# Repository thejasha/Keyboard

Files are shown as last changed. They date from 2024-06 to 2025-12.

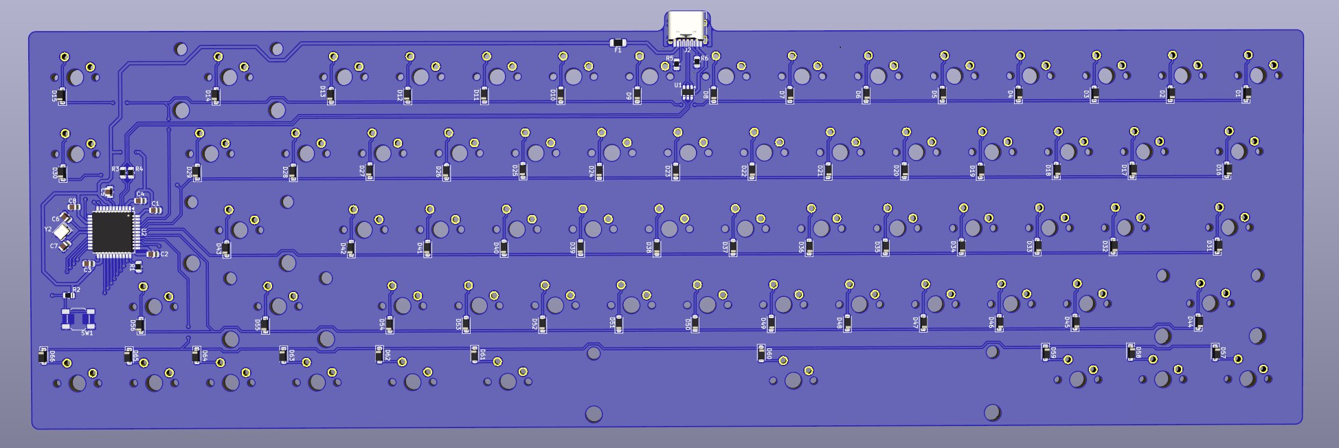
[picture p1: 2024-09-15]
Boardback.jpg

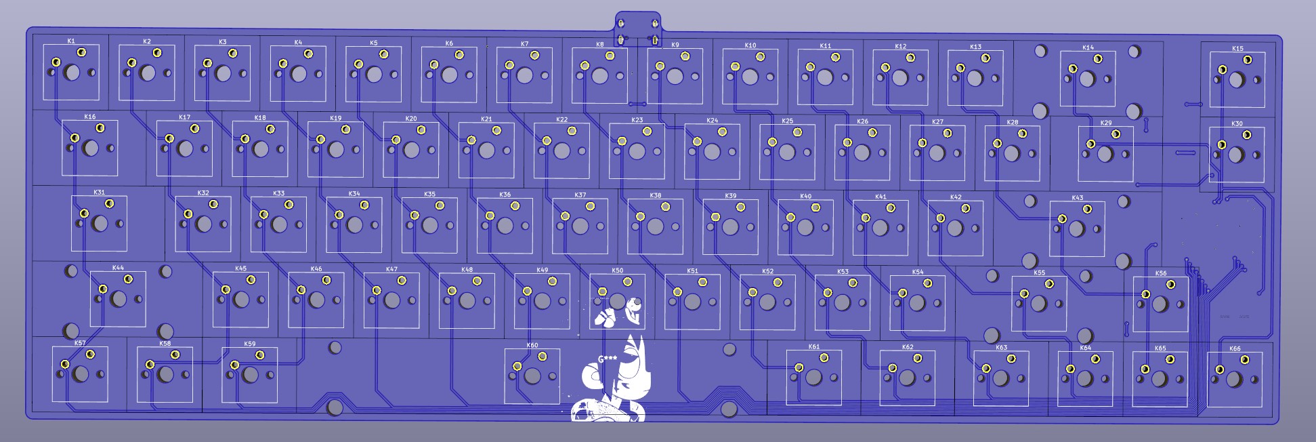
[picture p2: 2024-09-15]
Boardfront.jpg

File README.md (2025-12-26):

# Keyboard

Leopold fC660m schematic and PCB layout which are contained in 65 folder - can import whole folder as project in Kicad.



Boardfront



## Firmware
Download QMK MSYS, compile aacustomboard, and then flash it on MCU (Follow documenation on QMK site). aacustomboard files will only work the exact pinout from 65 files.

https://docs.qmk.fm/newbs_getting_started 

board

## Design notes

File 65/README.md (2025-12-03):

First attempt at making a Leopold fc660m style board, will not be doing leds for now.

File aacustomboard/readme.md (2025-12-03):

# aacustomboard

aacustomboard

*A short description of the keyboard/project*

* Keyboard Maintainer: [Josh Amann](https://github.com/thejasha/)
* Hardware Supported: *The PCBs, controllers supported*
* Hardware Availability: *Manufacter the 65 kicad file lol*

Make example for this keyboard (after setting up your build environment):

    make aacustomboard:default

Flashing example for this keyboard:

    make aacustomboard:default:flash

See the [build environment setup](https://docs.qmk.fm/#/getting_started_build_tools) and the [make instructions](https://docs.qmk.fm/#/getting_started_make_guide) for more information. Brand new to QMK? Start with our [Complete Newbs Guide](https://docs.qmk.fm/#/newbs).

## Bootloader

Enter the bootloader in 3 ways:

* **Bootmagic reset**: Hold down the key at (0,0) in the matrix (usually the top left key or Escape) and plug in the keyboard
* **Physical reset button**: Briefly press the button on the back of the PCB - some may have pads you must short instead [THIS ONE EASY]
* **Keycode in layout**: Press the key mapped to `QK_BOOT` if it is available

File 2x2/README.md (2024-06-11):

# Keyboard
First attempt using kicad. Learning how to design schematic and pcb by making a 2x2 board.

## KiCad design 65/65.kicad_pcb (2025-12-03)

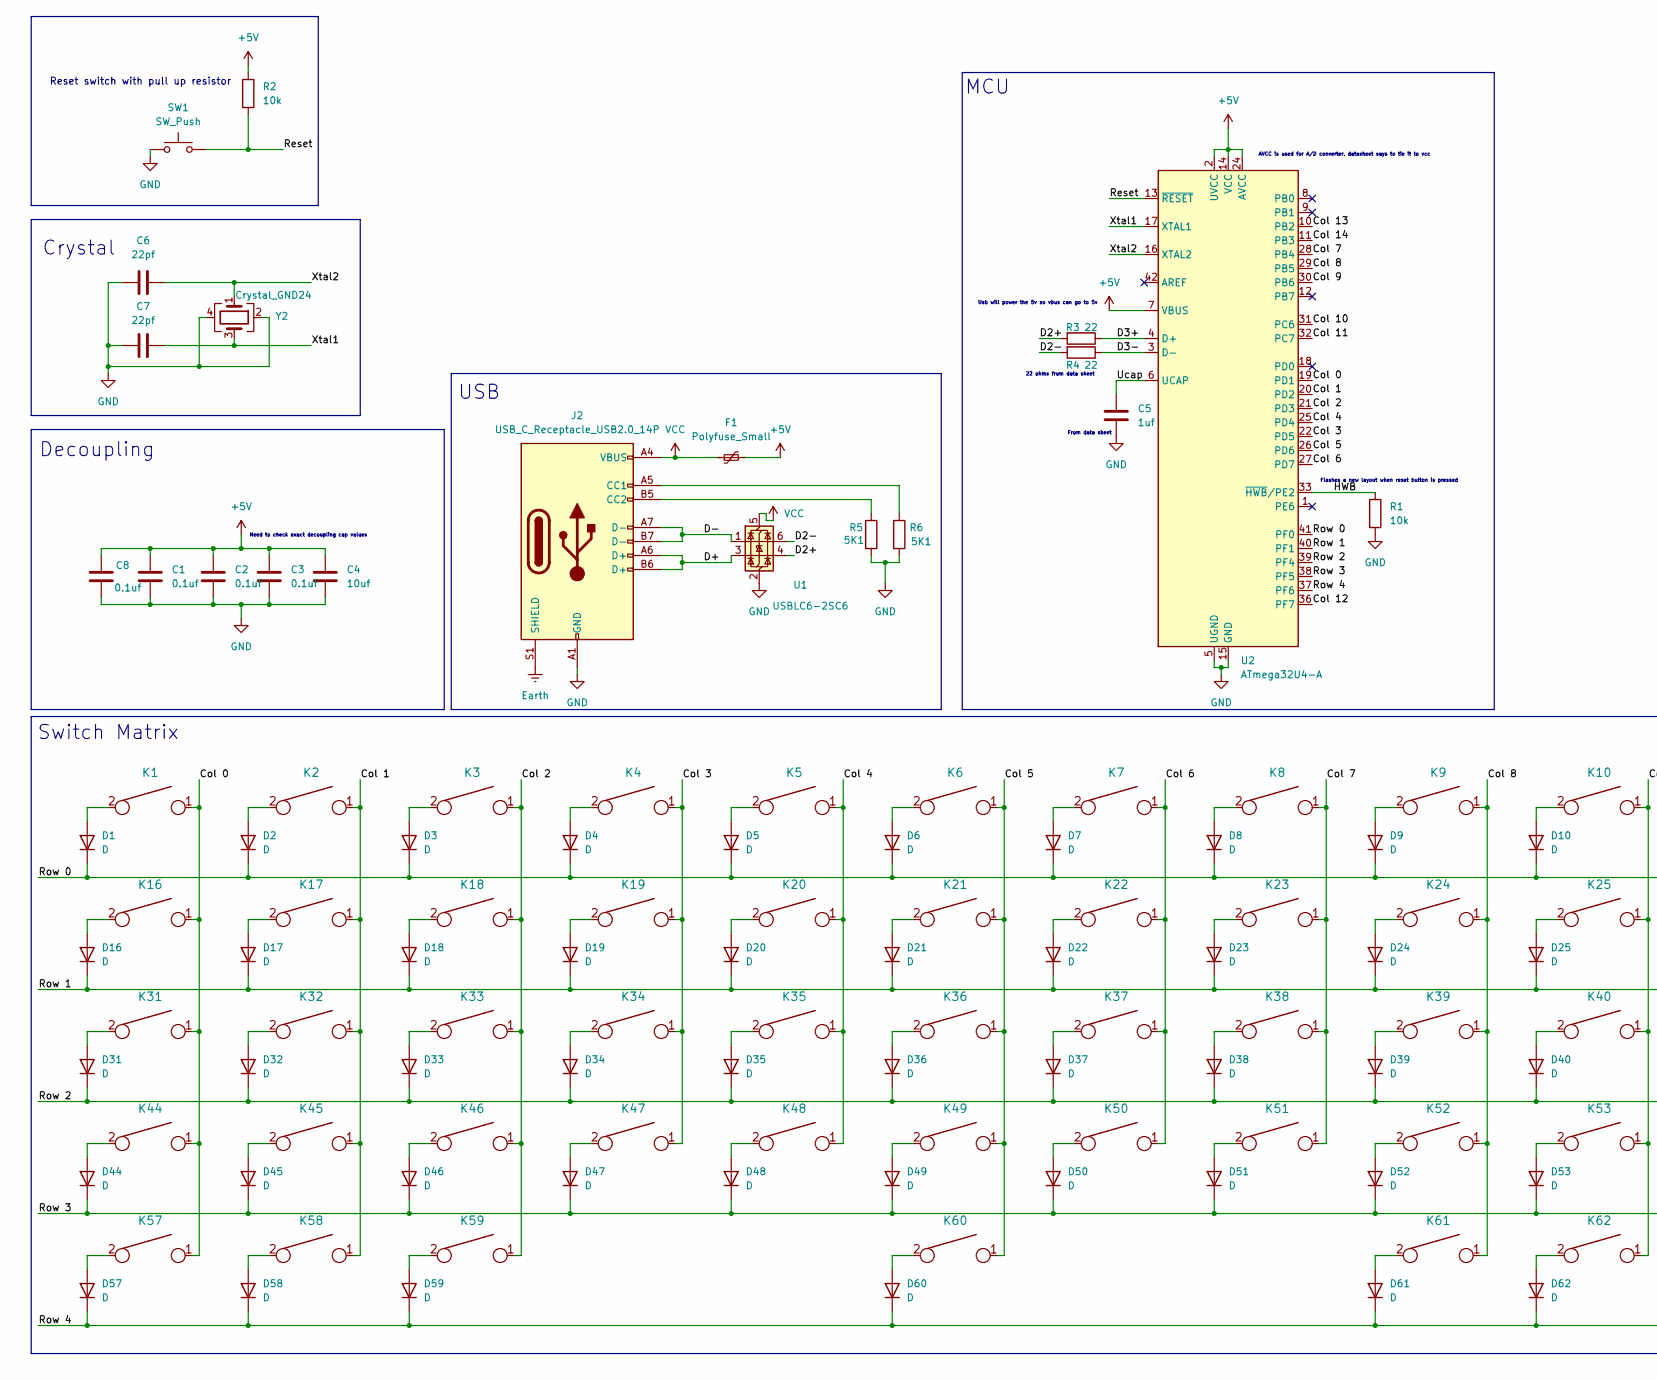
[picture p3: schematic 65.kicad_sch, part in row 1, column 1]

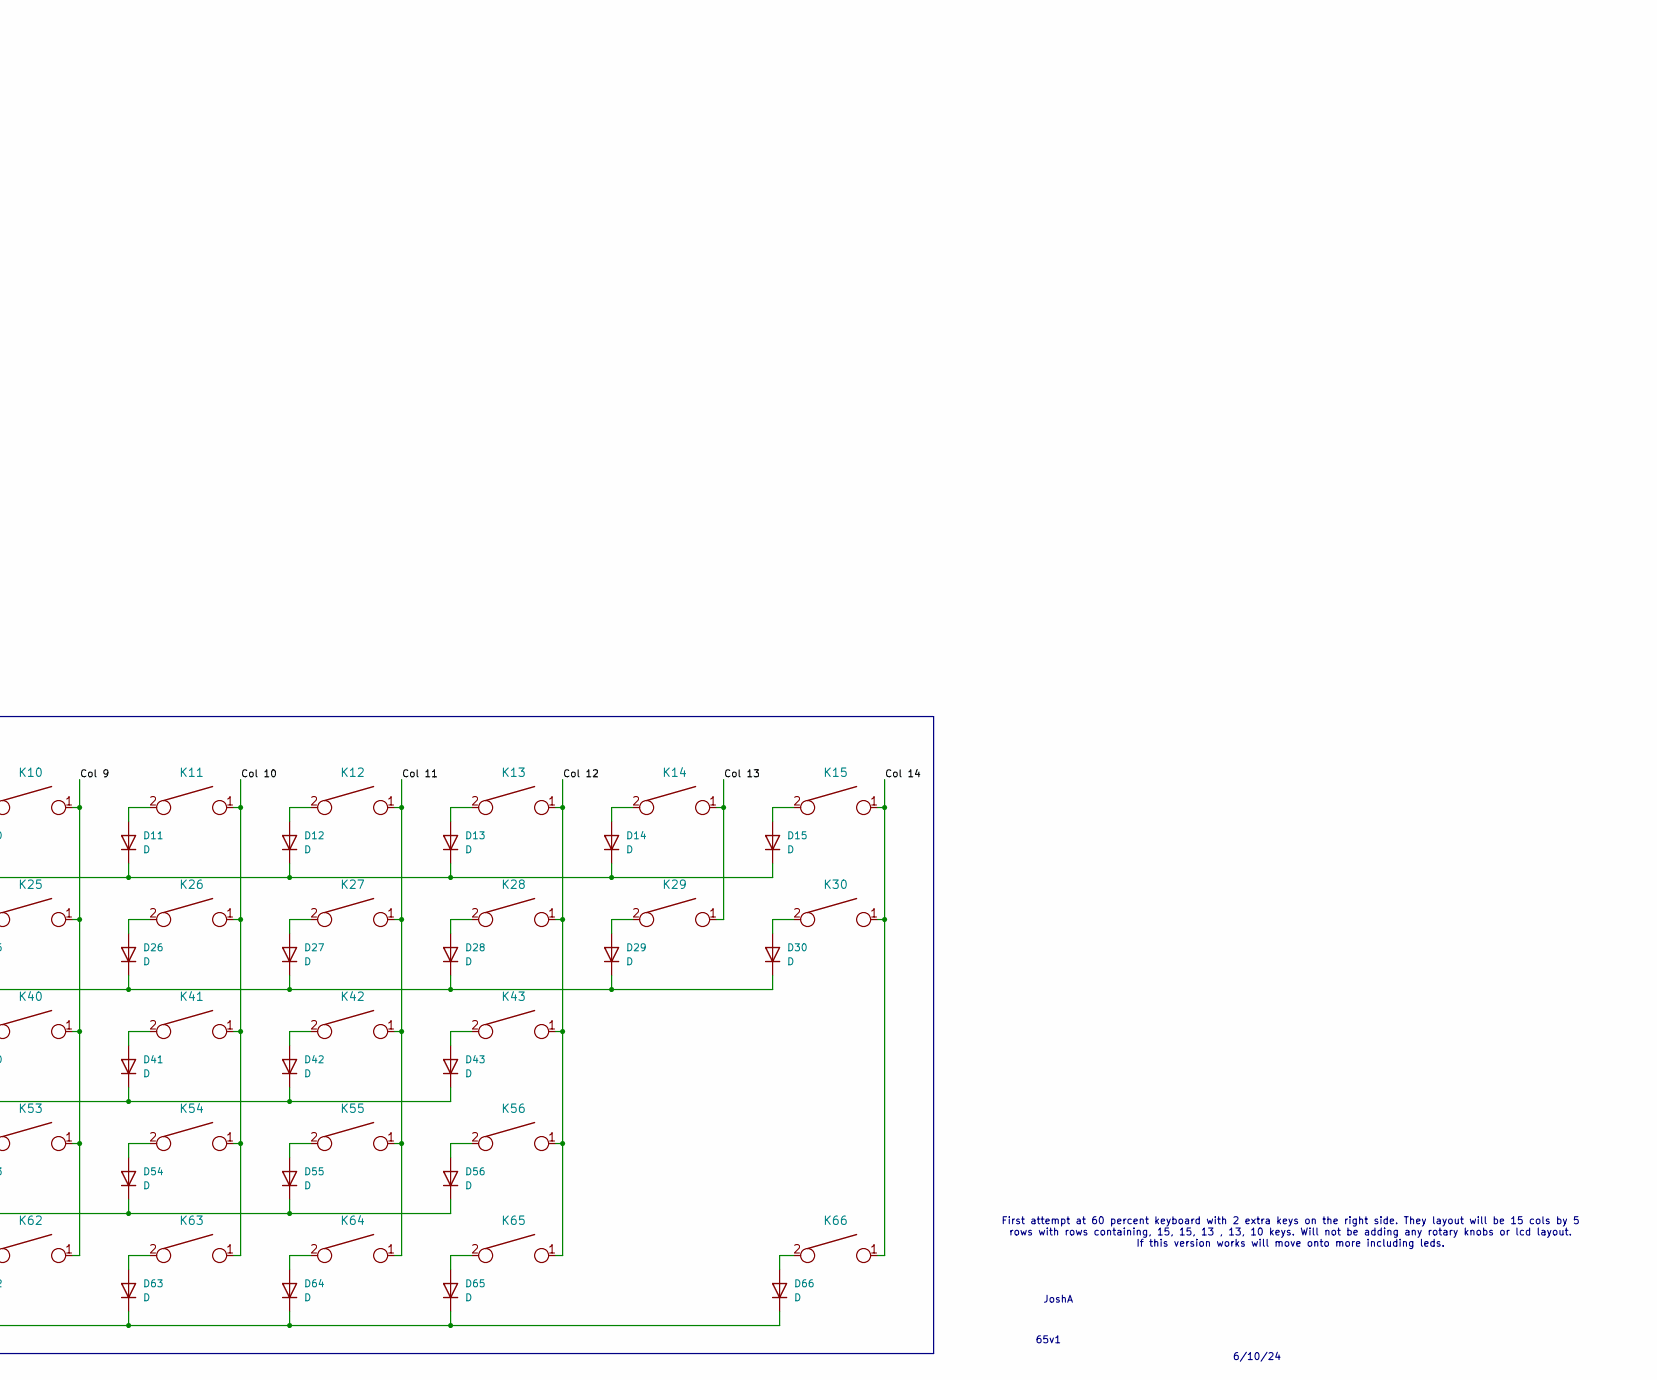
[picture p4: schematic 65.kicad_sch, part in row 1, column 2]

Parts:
C1, C2, C3, C8: 0.1uf; C_0805_2012Metric
C4: 10uf; C_0805_2012Metric
C5: 1uf; C_0805_2012Metric
C6, C7: 22pf; C_0805_2012Metric
D1, D2, D3, D4, D5, D6, D7, D8, D9, D10, D11, D12, D13, D14, D15, D16, D17, D18, D19, D20, D21, D22, D23, D24, D25, D26, D27, D28, D29, D30, D31, D32, D33, D34, D35, D36, D37, D38, D39, D40, D41, D42, D43, D44, D45, D46, D47, D48, D49, D50, D51, D52, D53, D54, D55, D56, D57, D58, D59, D60, D61, D62, D63, D64, D65, D66: D; D_SOD-123
F1: Polyfuse_Small; Fuse_1206_3216Metric
J2: USB_C_Receptacle_USB2.0_14P; USB_C_Receptacle_HRO_TYPE-C-31-M-12
K1: ESC; SW_Cherry_MX_1.00u_PCB
K2: 1!; SW_Cherry_MX_1.00u_PCB
K3: 2@; SW_Cherry_MX_1.00u_PCB
K4: 3#; SW_Cherry_MX_1.00u_PCB
K5: 4$; SW_Cherry_MX_1.00u_PCB
K6: 5%; SW_Cherry_MX_1.00u_PCB
K7: 6^; SW_Cherry_MX_1.00u_PCB
K8: 7&; SW_Cherry_MX_1.00u_PCB
K9: 8*; SW_Cherry_MX_1.00u_PCB
K10: 9(; SW_Cherry_MX_1.00u_PCB
K11: 0); SW_Cherry_MX_1.00u_PCB
K12: -_; SW_Cherry_MX_1.00u_PCB
K13: +=; SW_Cherry_MX_1.00u_PCB
K14: Backspace; SW_Cherry_MX_2.00u_PCB
K15: Delete; SW_Cherry_MX_1.00u_PCB
K16: Tab; SW_Cherry_MX_1.50u_PCB
K17: Q; SW_Cherry_MX_1.00u_PCB
K18: W; SW_Cherry_MX_1.00u_PCB
K19: E; SW_Cherry_MX_1.00u_PCB
K20: R; SW_Cherry_MX_1.00u_PCB
K21: T; SW_Cherry_MX_1.00u_PCB
K22: Y; SW_Cherry_MX_1.00u_PCB
K23: U; SW_Cherry_MX_1.00u_PCB
K24: I; SW_Cherry_MX_1.00u_PCB
K25: O; SW_Cherry_MX_1.00u_PCB
K26: P; SW_Cherry_MX_1.00u_PCB
K27: [{; SW_Cherry_MX_1.00u_PCB
K28: ]}; SW_Cherry_MX_1.00u_PCB
K29: \|; SW_Cherry_MX_1.50u_PCB
K30: Home; SW_Cherry_MX_1.00u_PCB
K31: Caps; SW_Cherry_MX_1.75u_PCB
K32: A; SW_Cherry_MX_1.00u_PCB
K33: S; SW_Cherry_MX_1.00u_PCB
K34: D; SW_Cherry_MX_1.00u_PCB
K35: F; SW_Cherry_MX_1.00u_PCB
K36: G; SW_Cherry_MX_1.00u_PCB
K37: H; SW_Cherry_MX_1.00u_PCB
K38: J; SW_Cherry_MX_1.00u_PCB
K39: K; SW_Cherry_MX_1.00u_PCB
K40: L; SW_Cherry_MX_1.00u_PCB
K41: ;:; SW_Cherry_MX_1.00u_PCB
K42: '"; SW_Cherry_MX_1.00u_PCB
K43: Enter; SW_Cherry_MX_2.25u_PCB
K44: LShift; SW_Cherry_MX_2.25u_PCB
K45: Z; SW_Cherry_MX_1.00u_PCB
K46: X; SW_Cherry_MX_1.00u_PCB
K47: C; SW_Cherry_MX_1.00u_PCB
K48: V; SW_Cherry_MX_1.00u_PCB
K49: B; SW_Cherry_MX_1.00u_PCB
K50: N; SW_Cherry_MX_1.00u_PCB
K51: M; SW_Cherry_MX_1.00u_PCB
K52: ,<; SW_Cherry_MX_1.00u_PCB
K53: .>; SW_Cherry_MX_1.00u_PCB
K54: /?; SW_Cherry_MX_1.00u_PCB
K55: RShift; SW_Cherry_MX_2.25u_PCB
K56: Up; SW_Cherry_MX_1.00u_PCB
K57: LCtrl; SW_Cherry_MX_1.25u_PCB
K58: Windows; SW_Cherry_MX_1.00u_PCB
K59: LAlt; SW_Cherry_MX_1.25u_PCB
K60: Space; SW_Cherry_MX_6.25u_PCB
K61: RAlt; SW_Cherry_MX_1.25u_PCB
K62: Fn; SW_Cherry_MX_1.25u_PCB
K63: RCtrl; SW_Cherry_MX_1.25u_PCB
K64: Left; SW_Cherry_MX_1.00u_PCB
K65: Down; SW_Cherry_MX_1.00u_PCB
K66: Right; SW_Cherry_MX_1.00u_PCB
R1, R2: 10k; R_0805_2012Metric
R3, R4: 22; R_0805_2012Metric
R5, R6: 5K1; R_0805_2012Metric
SW1: SW_Push; SW_SPST_SKQG_WithStem
U1: USBLC6-2SC6; SOT-23-6
U2: ATmega32U4-A; TQFP-44_10x10mm_P0.8mm
Y2: Crystal_GND24; Crystal_SMD_3225-4Pin_3.2x2.5mm

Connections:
+5V: C1.1, C2.1, C3.1, C4.1, C8.1, F1.2, R2.1, U2.2 (UVCC), U2.7 (VBUS), U2.14 (VCC), U2.24 (AVCC), U2.34 (VCC), U2.44 (AVCC)
/Col 0: K1.1, K16.1, K31.1, K44.1, K57.1, U2.19 (PD1)
/Col 1: K2.1, K17.1, K32.1, K45.1, K58.1, U2.20 (PD2)
/Col 2: K3.1, K18.1, K33.1, K46.1, K59.1, U2.21 (PD3)
/Col 3: K4.1, K19.1, K34.1, K47.1, U2.22 (PD5)
/Col 4: K5.1, K20.1, K35.1, K48.1, U2.25 (PD4)
/Col 5: K6.1, K21.1, K36.1, K49.1, K60.1, U2.26 (PD6)
/Col 6: K7.1, K22.1, K37.1, K50.1, U2.27 (PD7)
/Col 7: K8.1, K23.1, K38.1, K51.1, U2.28 (PB4)
/Col 8: K9.1, K24.1, K39.1, K52.1, K61.1, U2.29 (PB5)
/Col 9: K10.1, K25.1, K40.1, K53.1, K62.1, U2.30 (PB6)
/Col 10: K11.1, K26.1, K41.1, K54.1, K63.1, U2.31 (PC6)
/Col 11: K12.1, K27.1, K42.1, K55.1, K64.1, U2.32 (PC7)
/Col 12: K13.1, K28.1, K43.1, K56.1, K65.1, U2.36 (PF7)
/Col 13: K14.1, K29.1, U2.10 (PB2)
/Col 14: K15.1, K30.1, K66.1, U2.11 (PB3)
/D2+: R3.2, U1.4 (I/O2)
/D2-: R4.2, U1.6 (I/O1)
/D3+: R3.1, U2.4 (D+)
/D3-: R4.1, U2.3 (D-)
/D+: J2.A6 (D+), J2.B6 (D+), U1.3 (I/O2)
/D-: J2.A7 (D-), J2.B7 (D-), U1.1 (I/O1)
/HWB: R1.1, U2.33 (~HWB/PE2)
/Reset: R2.2, SW1.2, U2.13 (~RESET)
/Row 0: D1.1 (K), D2.1 (K), D3.1 (K), D4.1 (K), D5.1 (K), D6.1 (K), D7.1 (K), D8.1 (K), D9.1 (K), D10.1 (K), D11.1 (K), D12.1 (K), D13.1 (K), D14.1 (K), D15.1 (K), U2.41 (PF0)
/Row 1: D16.1 (K), D17.1 (K), D18.1 (K), D19.1 (K), D20.1 (K), D21.1 (K), D22.1 (K), D23.1 (K), D24.1 (K), D25.1 (K), D26.1 (K), D27.1 (K), D28.1 (K), D29.1 (K), D30.1 (K), U2.40 (PF1)
/Row 2: D31.1 (K), D32.1 (K), D33.1 (K), D34.1 (K), D35.1 (K), D36.1 (K), D37.1 (K), D38.1 (K), D39.1 (K), D40.1 (K), D41.1 (K), D42.1 (K), D43.1 (K), U2.39 (PF4)
/Row 3: D44.1 (K), D45.1 (K), D46.1 (K), D47.1 (K), D48.1 (K), D49.1 (K), D50.1 (K), D51.1 (K), D52.1 (K), D53.1 (K), D54.1 (K), D55.1 (K), D56.1 (K), U2.38 (PF5)
/Row 4: D57.1 (K), D58.1 (K), D59.1 (K), D60.1 (K), D61.1 (K), D62.1 (K), D63.1 (K), D64.1 (K), D65.1 (K), D66.1 (K), U2.37 (PF6)
/Ucap: C5.1, U2.6 (UCAP)
/Xtal1: C7.1, U2.17 (XTAL1), Y2.3
/Xtal2: C6.1, U2.16 (XTAL2), Y2.1
Earth: J2.S1 (SHIELD)
GND: C1.2, C2.2, C3.2, C4.2, C5.2, C6.2, C7.2, C8.2, J2.A1 (GND), J2.A12 (GND), J2.B1 (GND), J2.B12 (GND), R1.2, R5.2, R6.2, SW1.1, U1.2 (GND), U2.5 (UGND), U2.15 (GND), U2.23 (GND), U2.35 (GND), U2.43 (GND), Y2.2, Y2.4
unnamed: D1.2 (A), K1.2
unnamed: D2.2 (A), K2.2
unnamed: D3.2 (A), K3.2
unnamed: D4.2 (A), K4.2
unnamed: D5.2 (A), K5.2
unnamed: D6.2 (A), K6.2
unnamed: D7.2 (A), K7.2
unnamed: D8.2 (A), K8.2
unnamed: D9.2 (A), K9.2
unnamed: D10.2 (A), K10.2
unnamed: D11.2 (A), K11.2
unnamed: D12.2 (A), K12.2
unnamed: D13.2 (A), K13.2
unnamed: D14.2 (A), K14.2
unnamed: D15.2 (A), K15.2
unnamed: D16.2 (A), K16.2
unnamed: D17.2 (A), K17.2
unnamed: D18.2 (A), K18.2
unnamed: D19.2 (A), K19.2
unnamed: D20.2 (A), K20.2
unnamed: D21.2 (A), K21.2
unnamed: D22.2 (A), K22.2
unnamed: D23.2 (A), K23.2
unnamed: D24.2 (A), K24.2
unnamed: D25.2 (A), K25.2
unnamed: D26.2 (A), K26.2
unnamed: D27.2 (A), K27.2
unnamed: D28.2 (A), K28.2
unnamed: D29.2 (A), K29.2
unnamed: D30.2 (A), K30.2
unnamed: D31.2 (A), K31.2
unnamed: D32.2 (A), K32.2
unnamed: D33.2 (A), K33.2
unnamed: D34.2 (A), K34.2
unnamed: D35.2 (A), K35.2
unnamed: D36.2 (A), K36.2
unnamed: D37.2 (A), K37.2
unnamed: D38.2 (A), K38.2
unnamed: D39.2 (A), K39.2
unnamed: D40.2 (A), K40.2
unnamed: D41.2 (A), K41.2
unnamed: D42.2 (A), K42.2
unnamed: D43.2 (A), K43.2
unnamed: D44.2 (A), K44.2
unnamed: D45.2 (A), K45.2
unnamed: D46.2 (A), K46.2
unnamed: D47.2 (A), K47.2
unnamed: D48.2 (A), K48.2
unnamed: D49.2 (A), K49.2
unnamed: D50.2 (A), K50.2
unnamed: D51.2 (A), K51.2
unnamed: D52.2 (A), K52.2
unnamed: D53.2 (A), K53.2
unnamed: D54.2 (A), K54.2
unnamed: D55.2 (A), K55.2
unnamed: D56.2 (A), K56.2
unnamed: D57.2 (A), K57.2
unnamed: D58.2 (A), K58.2
unnamed: D59.2 (A), K59.2
unnamed: D60.2 (A), K60.2
unnamed: D61.2 (A), K61.2
unnamed: D62.2 (A), K62.2
unnamed: D63.2 (A), K63.2
unnamed: D64.2 (A), K64.2
unnamed: D65.2 (A), K65.2
unnamed: D66.2 (A), K66.2
unnamed: J2.A5 (CC1), R6.1
unnamed: J2.B5 (CC2), R5.1
VCC: F1.1, J2.A4 (VBUS), J2.A9 (VBUS), J2.B4 (VBUS), J2.B9 (VBUS), U1.5 (VBUS)

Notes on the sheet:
6/10/24
Decoupling
Flashes a new layout when reset button is pressed
65v1
First attempt at 60 percent keyboard with 2 extra keys on the right side. They layout will be 15 cols by 5 rows with rows containing, 15, 15, 13 , 13, 10 keys. Will not be adding any rotary knobs or lcd layout. If this version works will move onto more including leds.
From data sheet
22 ohms from data sheet
Switch Matrix
AVCC is used for A/D converter, datasheet says to tie it to vcc
MCU
Usb will power the 5v so vbus can go to 5v
Reset switch with pull up resistor
USB
Need to check exact decoupling cap values
JoshA
Crystal

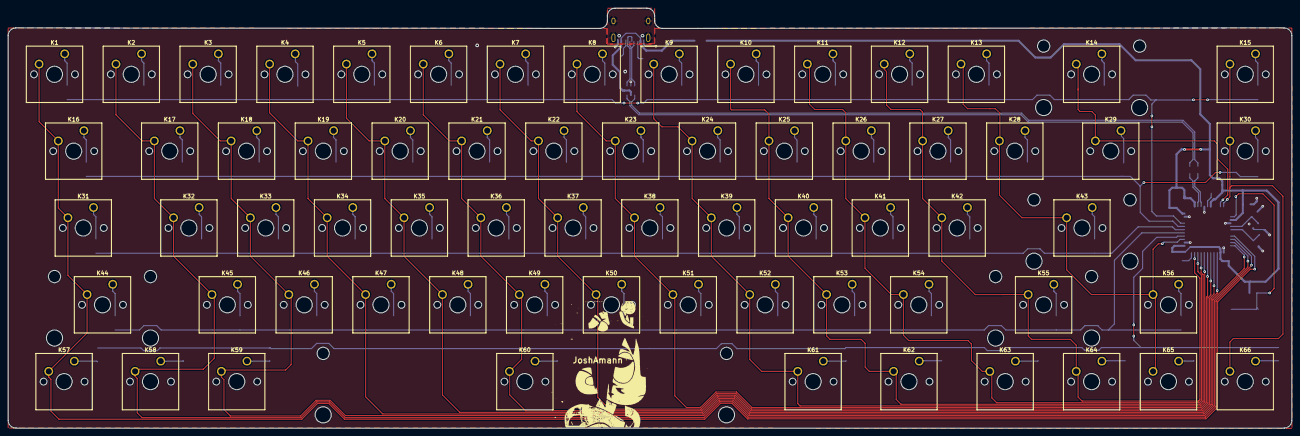
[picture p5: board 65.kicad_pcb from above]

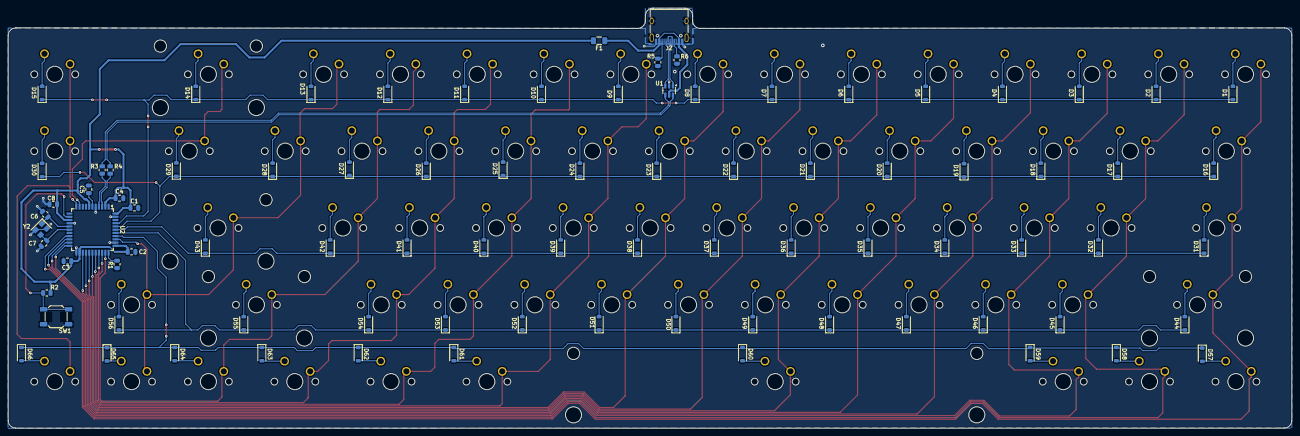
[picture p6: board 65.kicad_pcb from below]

Board: 2 copper layers, 318.3 x 104.1 mm, 153 parts (86 on the bottom side), 102 nets.

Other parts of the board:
JoshAmann: LOGO

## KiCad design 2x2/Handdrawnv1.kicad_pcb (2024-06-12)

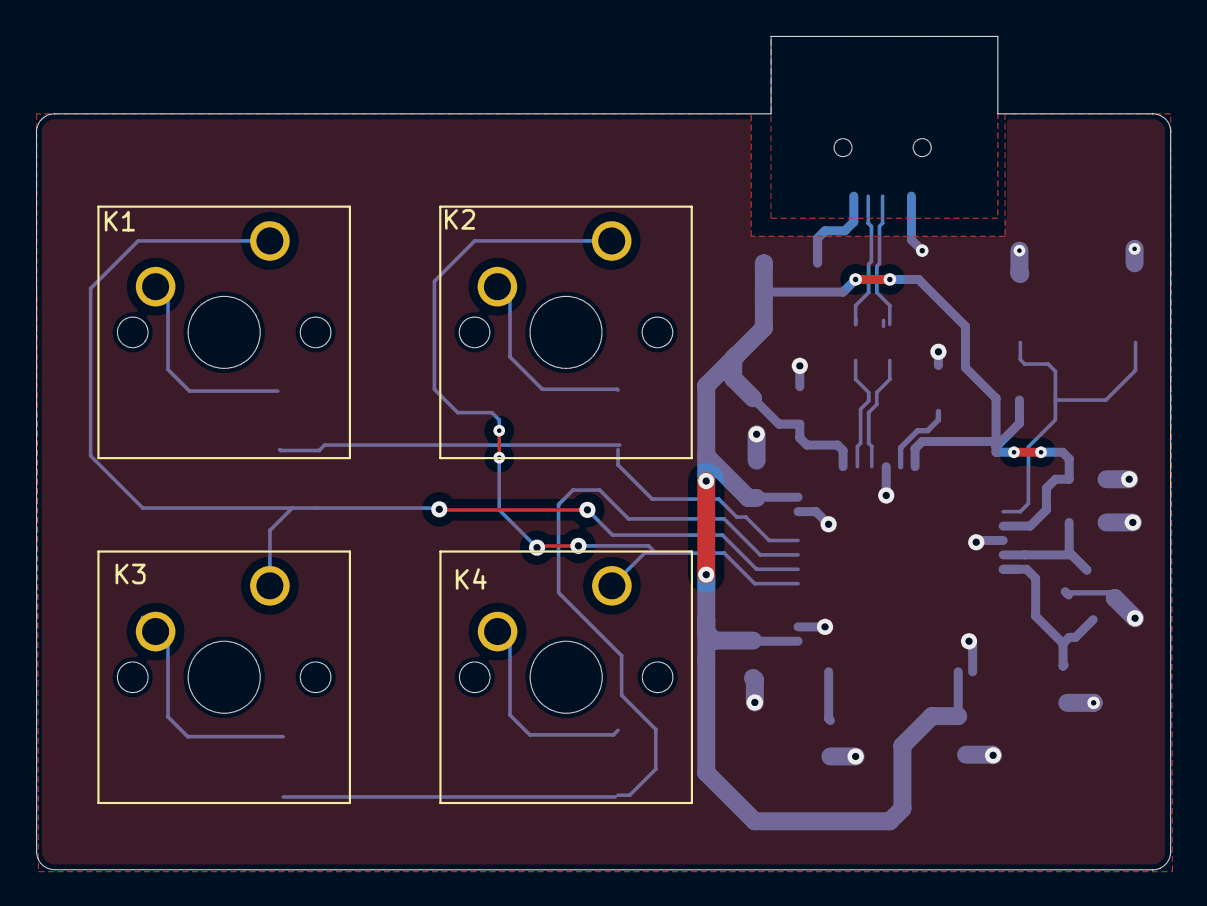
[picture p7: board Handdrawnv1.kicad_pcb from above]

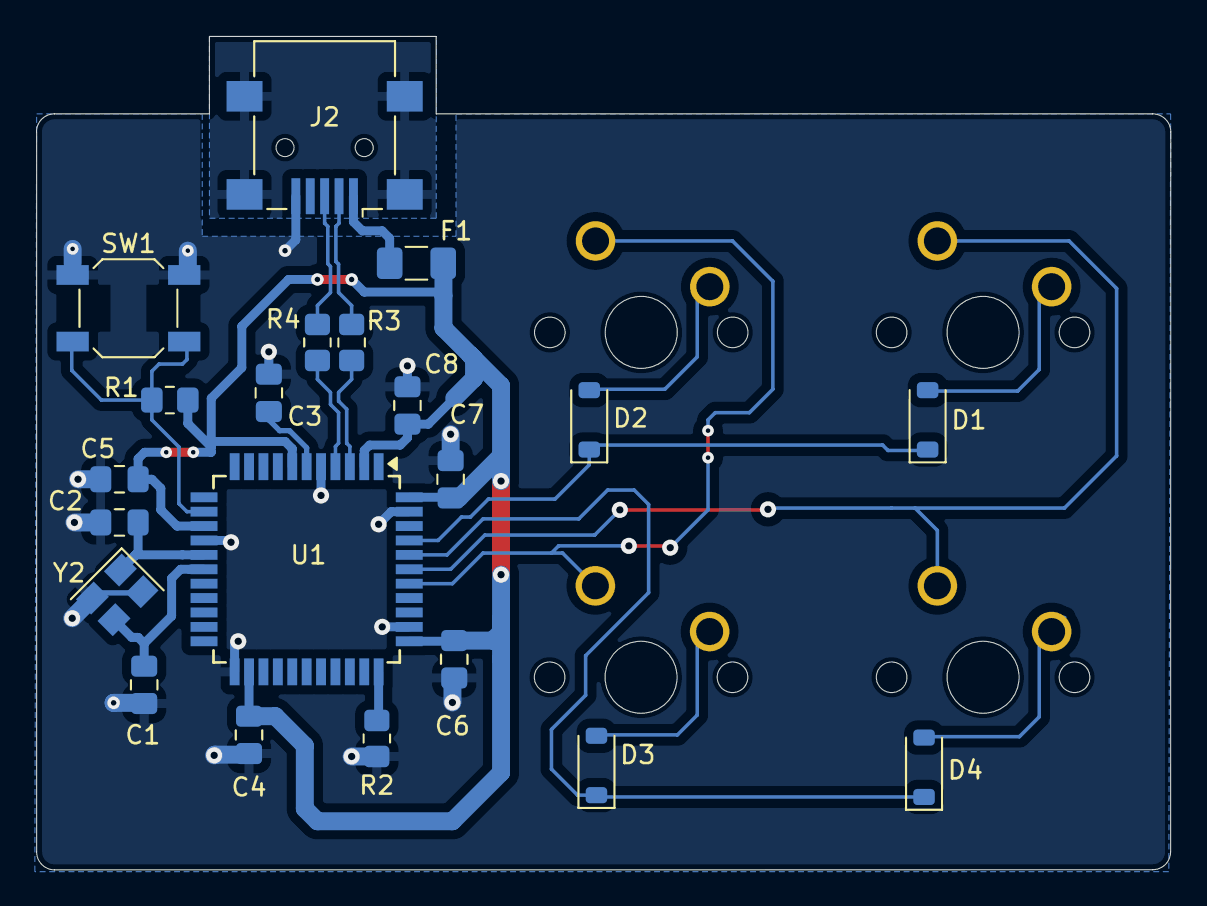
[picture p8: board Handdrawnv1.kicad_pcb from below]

Board: 2 copper layers, 63.0 x 46.3 mm, 25 parts (21 on the bottom side), 20 nets.

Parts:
C1, C2: 22p; C_0805_2012Metric_Pad1.18x1.45mm_HandSolder
C3: 1uF; C_0805_2012Metric_Pad1.18x1.45mm_HandSolder
C4, C5, C6, C7: 0.1uF; C_0805_2012Metric_Pad1.18x1.45mm_HandSolder
C8: 10uf; C_0805_2012Metric_Pad1.18x1.45mm_HandSolder
D1, D2, D3, D4: D; D_SOD-123
F1: 500mA; Fuse_1206_3216Metric_Pad1.42x1.75mm_HandSolder
J2: USB_B_Mini; USB_Mini-B_Lumberg_2486_01_Horizontal
K1, K2, K3, K4: KEYSW; SW_Cherry_MX_1.00u_PCB
R1, R2: 10k; R_0805_2012Metric_Pad1.20x1.40mm_HandSolder
R3, R4: 22; R_0805_2012Metric_Pad1.20x1.40mm_HandSolder
SW1: SW_PUSH; SW_SPST_SKQG_WithStem
U1: ATMEGA32U4; TQFP-44_10x10mm_P0.8mm
Y2: Crystal_GND24_Small; Crystal_SMD_3225-4Pin_3.2x2.5mm

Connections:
+5V: C4.1, C5.1, C6.1, C7.1, C8.1, F1.2, R1.1, U1.2 (UVcc), U1.7 (VBus), U1.14 (VCC), U1.24 (AVCC), U1.34 (VCC), U1.44 (AVCC)
/HWB: R2.1, U1.33 (~HWB/PE2)
/Reset: R1.2, SW1.2, U1.13 (~RESET)
/USBD2+: J2.3 (D+), R4.1
/USBD2-: J2.2 (D-), R3.1
/USBD+: R4.2, U1.4 (D+)
/USBD-: R3.2, U1.3 (D-)
/Ucap: C3.2, U1.6 (UCap)
/Xtal1: C2.1, U1.16 (XTAL1), Y2.1
/Xtal2: C1.1, U1.17 (XTAL2), Y2.3
/col 0: K1.1, K3.1, U1.39 (PF4)
/col 1: K2.1, K4.1, U1.38 (PF5)
/row 0: D1.1 (K), D2.1 (K), U1.41 (PF0)
/row 1: D3.1 (K), D4.1 (K), U1.40 (PF1)
GND: C1.2, C2.2, C3.1, C4.2, C5.2, C6.2, C7.2, C8.2, J2.5 (GND), R2.2, SW1.1, U1.5 (UGnd), U1.15 (GND), U1.23 (GND), U1.35 (GND), U1.43 (GND), Y2.2, Y2.4
unnamed: D1.2 (A), K1.2
unnamed: D2.2 (A), K2.2
unnamed: D3.2 (A), K4.2
unnamed: D4.2 (A), K3.2
VCC: F1.1, J2.1 (VBUS)

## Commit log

2024-06-11 added currently files working on
    [65.kicad_pcb, 65.kicad_sch, Handdrawnv1.kicad_pcb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]
2024-06-11 renamed folder
    [Handdrawnv1.kicad_pcb, Handdrawnv1.kicad_sch]
2024-06-12 almost finished the 2x2, will be working on the 65 now
    [65.kicad_pcb, 65.kicad_sch, Handdrawnv1.kicad_pcb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]
2024-06-13 Mainly did some usb stuff
    [65.kicad_pcb]
2024-06-14 swapped the footprint pads for the key swithces
    [65.kicad_pcb, 65.kicad_sch]
2024-06-14 Initial traces of switches
    [65.kicad_pcb]
2024-06-15 Traced monstly everything will need to fix parts
    [65.kicad_pcb, 65.kicad_sch]
2024-06-15 Added actual keyboard values to the pcb
    ;)
    [65.kicad_pcb, 65.kicad_sch]
2024-06-17 No errors on design checker, will now be moving around the traces to make the board look a lil nicer
    [65.kicad_pcb, 65.kicad_sch]
2025-12-03 added keyboard config firmware
    [65-B_Cu.gbr, 65-B_Mask.gbr, 65-B_Paste.gbr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]
2025-12-03 Update README with schematic and PCB layout info
    Added details about the schematic and PCB layout for the Leopold fC660m.
2025-12-09 Clarify README description of PCB layout
2025-12-09 Fix wording in firmware instructions
    Corrected the phrasing from 'flash it the board' to 'flash it on MCU'.
2025-12-26 Update README.md
    Added an image of the board to the README.
